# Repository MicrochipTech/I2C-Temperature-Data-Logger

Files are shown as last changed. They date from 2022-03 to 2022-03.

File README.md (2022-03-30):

# I<sup>2</sup>C Temperature Data Logger

Demo

## ABOUT
This demo implements an I<sup>2</sup>C temperature data logger. It is designed to teach the basics of I<sup>2</sup>C. The hardware uses the [**PIC18F13K50**](https://www.microchip.com/wwwproducts/en/PIC18F13K50) to communicate with the [**MCP9804**](https://www.microchip.com/wwwproducts/en/MCP9804) for the current temperature and logs that temperature using the [**24LC64**](https://www.microchip.com/wwwproducts/en/24LC64) 64-Kbit I<sup>2</sup>C Serial EEPROM. A AAA 1.5V battery, boosted to 3.3V by the [**MCP1640**](https://www.microchip.com/wwwproducts/en/MCP1640), is used to power the board. The software communicates  with the firmware using a USB Mini cable and the firmware can be programmed by using one of Microchip's many PICkit™ Programmers and Debuggers using the PICkit™ header.

### Hardware
- [**Schematic**](/Docs/Temperature%20Logger%20Schematic.pdf)
- [**BOM**](/Docs/Temperature%20Logger%20%20Bill%20of%20Materials.xls)
- [**PCB**](/PCB/I2C%20Temperature%20Logger.pdf)
- [**Gerbers**](/PCB/Gerber%20Files/05-07893-R1%20Gerbers.zip)

### Software
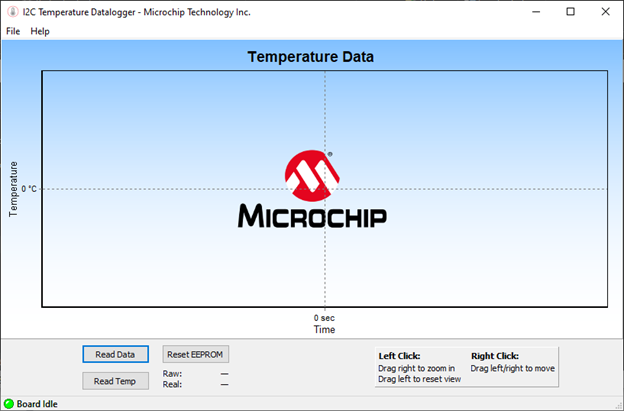
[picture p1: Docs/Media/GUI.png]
GUI

- [**Graphical User Interface**](/Software/I2C%20Temp%20Datalogger.exe)

### Firmware
- [**Firmware**](/Firmware/dist/Default/Production/Firmware.production.hex)

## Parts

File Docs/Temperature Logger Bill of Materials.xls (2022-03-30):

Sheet: BOM Report
M |  |  |  | Microchip Technology Inc. 2355 W. Chandler Blvd. Chandler, AZ 85224-6199
ASSEMBLY NUMBER: |  |  | 02-07893 | REV: | 1 |  |  |  | Bill of Materials
ASSEMBLY NAME: |  |  | PCB ASSEMBLY, I2C TEMPERATURE DATALOGGER
Item | Quantity | Designator |  | Description |  | Manufacturer | Manufacturer Part Number | Supplier | Supplier Part Number
1 | 1 | BT1 |  | HOLDER BATTERY 1CELL AAA PC MNT |  | Keystone Electronics | 2466 | Digi-Key | 2466K-ND
2 | 2 | C1, C4 |  | CAP CER 15PF 50V 5% NP0 0603 |  | TDK Corporation | C1608C0G1H150J | Digi-Key | 445-1271-1-ND
3 | 3 | C2, C5, C6 |  | CAP CER 10nF 50V 10% X7R 0603 |  | Murata Electronics North America | GRM188R71H103KA01D | Digi-Key | 490-1512-1-ND
4 | 1 | C3 |  | CAP CER 0.33uF 16V 10% X7R 0603 |  | Murata Electronics North America | GRM188R71C334KA01D | Mouser | 81-GRM188R71C334KA1D
5 | 2 | C7, C8 |  | CAP CER 10uF 6.3V X5R 20% 0805 |  | TDK Corporation | C2012X5R0J106M | Digi-Key | 445-1363-1-ND
6 | 2 | C9, C10 |  | CAP CER 2.2uF 16V Y5V -20%, +80% 0603 |  | TDK Corporation | C1608Y5V1C225Z | Digi-Key | 445-3451-1-ND
7 | 1 | D1 |  | LED CHIPLED 570NM GREEN 0603 SMD |  | OSRAM Opto Semiconductors Inc | LG Q971-KN-1 | Digi-Key | 475-1409-1-ND
8 | 1 | J1 |  | R/A BREAKAWAY HDR 6P |  | Molex | 22-28-8060 | Mouser | 538-22-28-8060
9 | 1 | J2 |  | CONN RECEPT MINI USB2.0 5POS |  | Hirose Electric Co Ltd | UX60-MB-5ST | Digi-Key | H2959CT-ND
10 | 1 | L1 |  | IND 1200mA, 4.7uH DCR Max=0.2, +/-30% |  | Wurth Electronics | 744029004 | Mouser | 710-744029004
11 | 1 | Q1 |  | MOSFET P-CH 20V 1.5A UFV |  | Toshiba | SSM5G10TU(TE85L,F) | Digi-Key | SSM5G10TU(TE85LF)CT-ND
12 | 2 | R1, R2 |  | RES 2.2K OHM 1/10W 5% 0603 SMD |  | Panasonic - ECG | ERJ-3GEYJ222V | Digi-Key | P2.2KGCT-ND
13 | 1 | R3 |  | RES 976K OHM 1/10W 1% 0603 SMD |  | Panasonic - ECG | ERJ-3EKF9763V | Digi-Key | P976KHCT-ND
14 | 1 | R4 |  | RES 562K OHM 1/10W 1% 0603 SMD |  | Panasonic - ECG | ERJ-3EKF5623V | Digi-Key | P562KHCT-ND
15 | 2 | R5, R7 |  | RES 10K OHM 1/10W 5% 0603 SMD |  | Panasonic - ECG | ERJ-3GEYJ103V | Digi-Key | P10KGCT-ND
16 | 1 | R6 |  | RES 270 OHM 1/10W 5% 0603 SMD |  | Panasonic - ECG | ERJ-3GEYJ271V | Digi-Key | P270GCT-ND
17 | 1 | U1 |  | IC PIC MCU FLASH 512KX8 20-QFN |  | Microchip Technology | PIC18F13K50-I/MQ | Microchip | PIC18F13K50-I/MQ
18 | 1 | U2 |  | IC EEPROM 64KBIT 400KHZ SOT23-5 |  | Microchip Technology | 24LC64T-E/OT | Microchip | 24LC64T-E/OT
19 | 1 | U3 |  | IC TEMP SENSOR I2C 2.7V 8DFN |  | Microchip Technology | MCP9804T-E/MC | Microchip | MCP9804T-E/MC
20 | 1 | U4 |  | IC BOOST SYNC ADJ 0.1A SOT23-6 |  | Microchip Technology | MCP1640T-I/CHY | Microchip | MCP1640T-I/CHY
21 | 1 | Y1 |  | CRYSTAL 12.000 MHZ 12PF SMD |  | TXC CORPORATION | 7V-12.000MAAE-T | Digi-Key | 887-1458-1-ND
 | 28

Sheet: Project Information
Project Full Path | C:\Memory\MASTERs\MASTERs 2012\1637I2C\Board\I2C Temperature Logger.PrjPCB
Project Filename | I2C Temperature Logger.PrjPCB
Variant Name | None
Data-Source Filename | I2C Temperature Logger.PrjPCB
Data-Source Full Path | C:\Memory\MASTERs\MASTERs 2012\1637I2C\Board\I2C Temperature Logger.PrjPCB
Title | I2C Temperature Datalogger
Total Quantity | 28
Drawing Number | 07893
Report Time | 5:13:59 PM
Report Date | 5/15/2012
Report Date & Tine | 5/15/2012 5:13:59 PM
Output Name | CM Bill of Materials
Output Type | BOM_PartType
Output Generator Name | BOM
Output Generator Description | Bill of Materials

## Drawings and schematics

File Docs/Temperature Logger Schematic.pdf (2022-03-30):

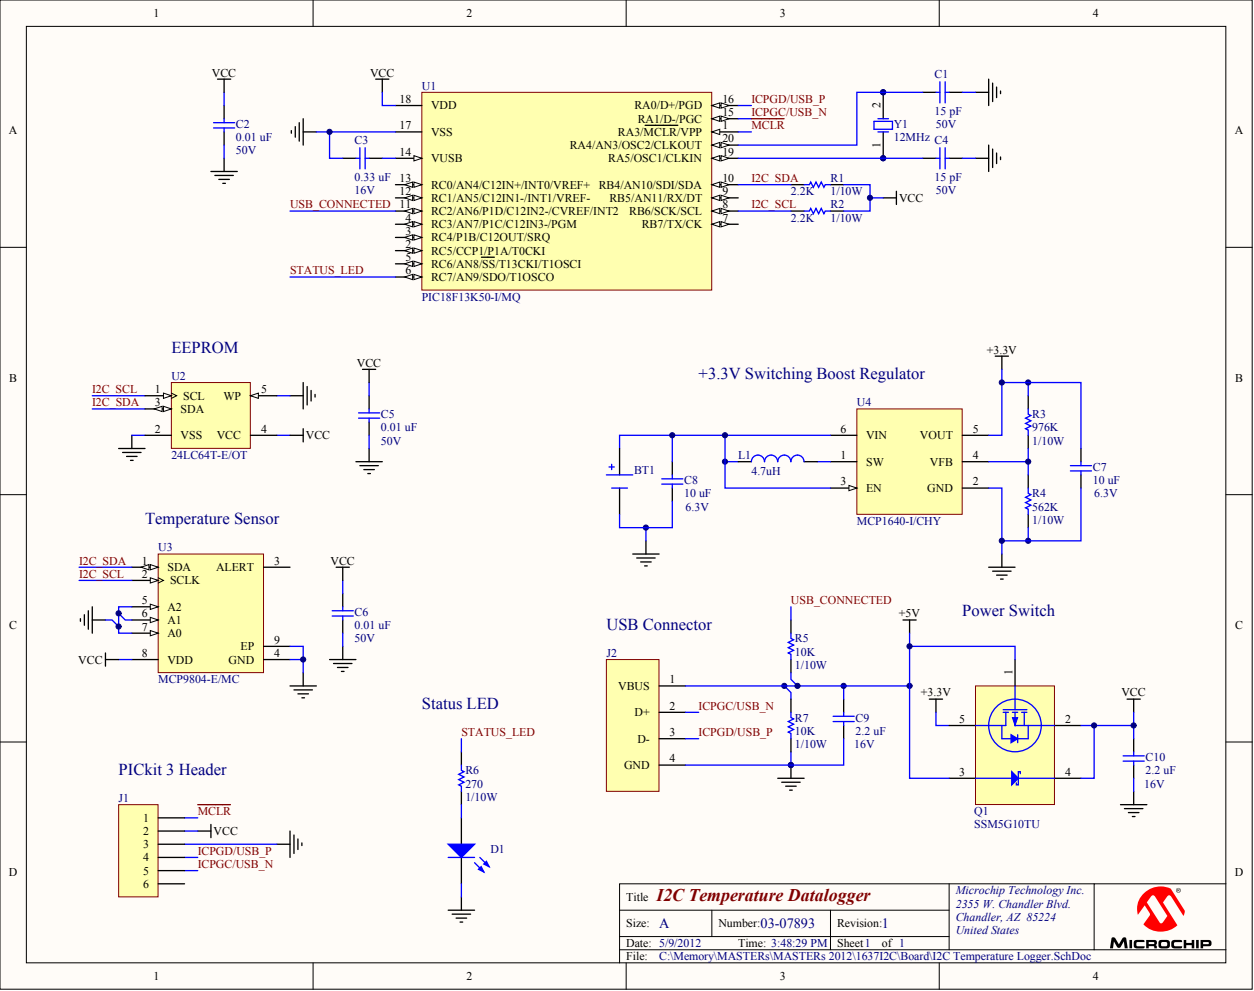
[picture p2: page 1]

Title I2C Temperature Datalogger | Microchip Technology Inc. 2355 W. Chandler Blvd. Chandler, AZ 85224 United States | 12

Size: A | Number: 03-07893 | Revision: 1
Date: 5/9/2012 Time: 3:48:29 PM | | Sheet 1 of 1

C:\Memory\MASTERs\MASTERs 2012\1637I2C\Board\I2C Temperature Logger.SchDoc

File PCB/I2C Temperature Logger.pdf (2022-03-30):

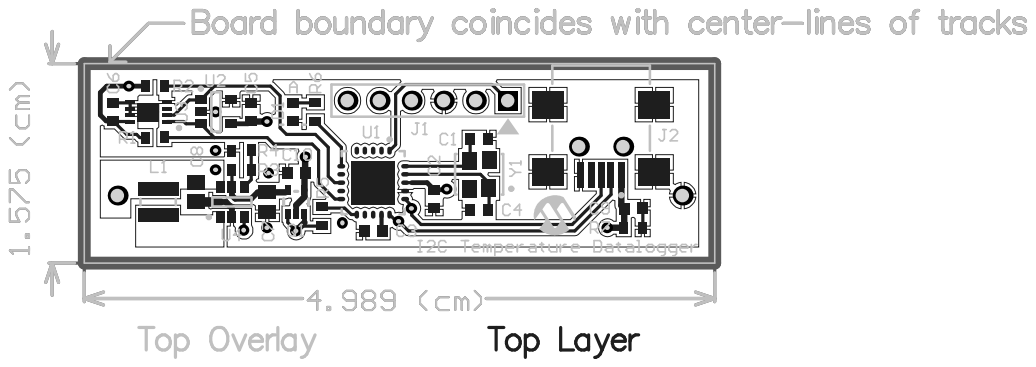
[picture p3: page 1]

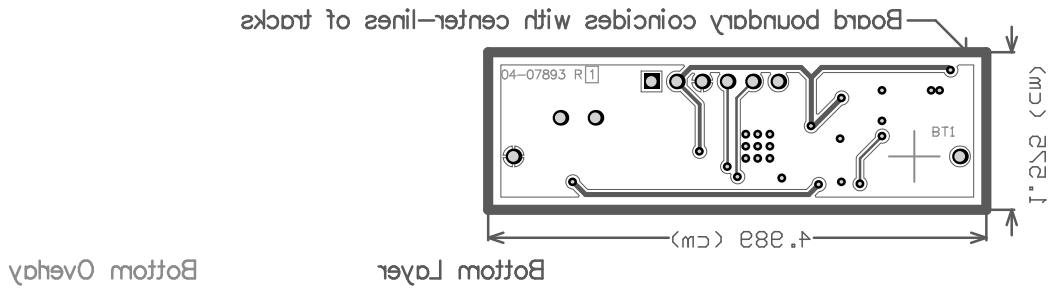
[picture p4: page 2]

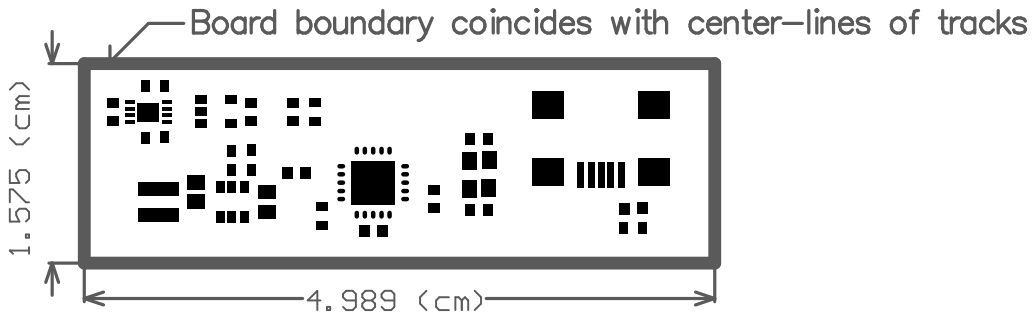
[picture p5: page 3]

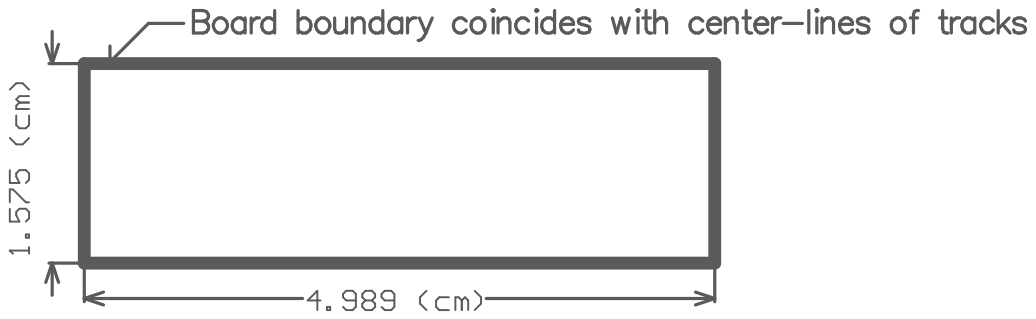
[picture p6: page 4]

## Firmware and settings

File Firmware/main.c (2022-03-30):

/*******************************************************************************
    (c) 2022 Microchip Technology Inc. and its subsidiaries.

    Subject to your compliance with these terms, you may use Microchip
    software and any derivatives exclusively with Microchip products. It is
    your responsibility to comply with third party license terms applicable to
    your use of third party software (including open source software) that may
    accompany Microchip software.

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
    IN NO EVENT WILL MICROCHIP BE LIABLE FOR ANY INDIRECT, SPECIAL, PUNITIVE,
    INCIDENTAL OR CONSEQUENTIAL LOSS, DAMAGE, COST OR EXPENSE OF ANY KIND
    WHATSOEVER RELATED TO THE SOFTWARE, HOWEVER CAUSED, EVEN IF MICROCHIP
    HAS BEEN ADVISED OF THE POSSIBILITY OR THE DAMAGES ARE FORESEEABLE. TO
    THE FULLEST EXTENT ALLOWED BY LAW, MICROCHIP'S TOTAL LIABILITY ON ALL
    CLAIMS IN ANY WAY RELATED TO THIS SOFTWARE WILL NOT EXCEED THE AMOUNT
    OF FEES, IF ANY, THAT YOU HAVE PAID DIRECTLY TO MICROCHIP FOR THIS
    SOFTWARE.
*******************************************************************************/

/** INCLUDES *******************************************************/
#include <xc.h>
#include "system.h"
#include "usb_config.h"
#include "usb.h"
#include "usb_device_hid.h"
#include "HardwareProfile.h"
#include "i2c_module.h"
#include "stdbool.h"

/** C O N S T A N T S **********************************************/
#define USB_EE_READ_CMD         0x80
#define USB_TEMP_READ_CMD       0x81
#define USB_EE_RESET_CMD        0x82

#define USB_EE_RESET_UNLOCK1    0x55
#define USB_EE_RESET_UNLOCK2    0xAA


/** T Y P E D E F S ************************************************/
typedef enum
{
    LOG_MODE,                   // Temperature logging mode
    USB_MODE                    // USB processing mode
} APP_STATES;

/** V A R I A B L E S **********************************************/

unsigned char ReceivedDataBuffer[HID_INT_OUT_EP_SIZE] @ HID_OUT_DATA_BUFFER_ADDRESS;
unsigned char ToSendDataBuffer[HID_INT_IN_EP_SIZE] @ HID_IN_DATA_BUFFER_ADDRESS;

volatile USB_HANDLE USBOutHandle = 0;
volatile USB_HANDLE USBInHandle = 0;

APP_STATES appState = LOG_MODE;

// To save power by reducing the number of EEPROM writes performed, temperature
//   temperature readings are buffered until a full EEPROM page of data is ready.
//   Then the entire buffer is written in a single operation.
uint8_t logBuffer[I2C_EEPROM_PAGE_SIZE]; // Datalogging buffer
uint8_t logBufferIndex;           // Index of current position in datalog buffer
uint16_union logEEAddress;        // Array address for next EEPROM page write

uint8_t logIntervalCount;         // Temperature reading interval counter

extern volatile USB_HANDLE USBOutHandle;
extern volatile USB_HANDLE USBInHandle;

/** P R I V A T E   P R O T O T Y P E S ****************************/
void HighPriorityISRCode(void);
void LowPriorityISRCode(void);
void InitializeSystem(void);
void UserSystemInit(void);
void LogModeInit(void);
void USBModeInit(void);
void ProcessLogIO(void);
void ProcessUSBIO(void);
void FindLastLogEntry(void);
void ResetEEPROMData(void);
void USBCBSendResume(void);
void USBCB_SOF_Handler(void);
void USBCBSuspend(void);
void USBCBWakeFromSuspend(void);
void USBCBInitEP(void);
void USBCBStdSetDscHandler(void);
void USBCBCheckOtherReq(void);
void USBCBErrorHandler(void);


MAIN_RETURN main(void)
{
    // Initialize the general system resources
    InitializeSystem();

    // Determine which state to enter initially and enter it
    if (USB_BUS_SENSE == 1)
        USBModeInit();
    else
        LogModeInit();

    while(1)
    {
        // Ensure status LED is off after any previous temperature readings
        STATUS_LED_LAT = STATUS_LED_OFF;

        // If USB cable is plugged in, then temperature readings are suspended
        //   and we're operating in data transfer mode
        if (USB_BUS_SENSE == 1)
        {
            // If we're not already in USB mode, switch to it now
            if (appState != USB_MODE)
                USBModeInit();

            // Process application-related USB tasks
            ProcessUSBIO();
        }
        // If USB cable is not plugged in, then we need to periodically read
        //   and log the current temperature
        else
        {
            // If we're not already in logging mode, switch to it now
            if (appState != LOG_MODE)
                LogModeInit();

            // Process datalogging tasks
            ProcessLogIO();

            // Datalogging-related tasks are now complete, enter idle mode until
            //   ECCP1 triggers to save power
            OSCCONbits.IDLEN = 1; // Ensure idle enable bit is set
            Sleep();            // Enter idle mode
            PIR1bits.CCP1IF = 0; // Clear CCP1IF flag for next loop
        }
    }//end while

}//end main


bool USER_USB_CALLBACK_EVENT_HANDLER(USB_EVENT event, void *pdata, uint16_t size)
{
    switch((int)event)
    {
        case EVENT_TRANSFER:
            break;

        case EVENT_SOF:            
            USBCB_SOF_Handler();
            break;

        case EVENT_SUSPEND:
            USBCBSuspend();
            break;

        case EVENT_RESUME:
            USBCBWakeFromSuspend();
            break;

        case EVENT_CONFIGURED:
            USBCBInitEP();
            break;

        case EVENT_SET_DESCRIPTOR:
            USBCBStdSetDscHandler();
            break;

        case EVENT_EP0_REQUEST:
            USBCBCheckOtherReq();
            break;

        case EVENT_BUS_ERROR:
            USBCBErrorHandler();
            break;

        case EVENT_TRANSFER_TERMINATED:
            break;

        default:
            break;
    }
    return true;
}



/********************************************************************
 * Function:        static void InitializeSystem(void)
 *
 * PreCondition:    None
 *
 * Input:           None
 *
 * Output:          None
 *
 * Side Effects:    None
 *
 * Overview:        InitializeSystem is a centralize initialization
 *                  routine. All required USB initialization routines
 *                  are called from here.
 *
 *                  User application initialization routine should
 *                  also be called from here.
 *
 * Note:            None
 *******************************************************************/
void InitializeSystem(void)
{
    // Switch from primary oscillator to internal oscillator, and disable
    //   primary oscillator and PLL to save power
    OSCCONbits.IRCF = 0x04;     // Set internal oscillator to 2 MHz
    OSCCONbits.SCS1 = 1;        // Select internal oscillator
    while (OSCCONbits.OSTS);    // Wait for clock switch to complete
    OSCCON2bits.PRI_SD = 0;     // Disable primary oscillator
    OSCTUNEbits.SPLLEN = 0;     // Disable PLL

    // Disable all analog inputs
    ANSEL = 0;
    ANSELH = 0;

//  The USB specifications require that USB peripheral devices must never source
//  current onto the Vbus pin.  Additionally, USB peripherals should not source
//  current on D+ or D- when the host/hub is not actively powering the Vbus line.
//  When designing a self powered (as opposed to bus powered) USB peripheral
//  device, the firmware should make sure not to turn on the USB module and D+
//  or D- pull up resistor unless Vbus is actively powered.  Therefore, the
//  firmware needs some means to detect when Vbus is being powered by the host.
//  A 5V tolerant I/O pin can be connected to Vbus (through a resistor), and
//  can be used to detect when Vbus is high (host actively powering), or low
//  (host is shut down or otherwise not supplying power).  The USB firmware
//  can then periodically poll this I/O pin to know when it is okay to turn on
//  the USB module/D+/D- pull up resistor.  When designing a purely bus powered
//  peripheral device, it is not possible to source current on D+ or D- when the
//  host is not actively providing power on Vbus. Therefore, implementing this
//  bus sense feature is optional.  This firmware can be made to use this bus
//  sense feature by making sure "USE_USB_BUS_SENSE_IO" has been defined in the
//  HardwareProfile.h file.
    #if defined(USE_USB_BUS_SENSE_IO)
    tris_usb_bus_sense = INPUT_PIN; // See HardwareProfile.h
    #endif

//  If the host PC sends a GetStatus (device) request, the firmware must respond
//  and let the host know if the USB peripheral device is currently bus powered
//  or self powered.  See chapter 9 in the official USB specifications for details
//  regarding this request.  If the peripheral device is capable of being both
//  self and bus powered, it should not return a hard coded value for this request.
//  Instead, firmware should check if it is currently self or bus powered, and
//  respond accordingly.  If the hardware has been configured like demonstrated
//  on the PICDEM FS USB Demo Board, an I/O pin can be polled to determine the
//  currently selected power source.  On the PICDEM FS USB Demo Board, "RA2"
//  is used for this purpose.  If using this feature, make sure "USE_SELF_POWER_SENSE_IO"
//  has been defined in HardwareProfile.h, and that an appropriate I/O pin has been mapped
//  to it in HardwareProfile.h.
    #if defined(USE_SELF_POWER_SENSE_IO)
    tris_self_power = INPUT_PIN; // See HardwareProfile.h
    #endif

    USBDeviceInit();            //usb_device.c.  Initializes USB module SFRs and firmware
                                //variables to known states.

    UserSystemInit();           // Perform app-related system initialization
}//end InitializeSystem

/******************************************************************************
 * Function:        void UserSystemInit(void)
 *
 * PreCondition:    None
 *
 * Input:           None
 *
 * Output:          None
 *
 * Side Effects:    None
 *
 * Overview:        This routine takes care of all of the application-related
 *                  system initialization.
 *
 * Note:            None
 *****************************************************************************/
void UserSystemInit(void)
{
    // Configure status LED pin
    STATUS_LED_LAT = STATUS_LED_OFF; // Turn LED off by default
    STATUS_LED_TRIS = OUTPUT_PIN; // Configure pin as an output

    // Initialize the I2C module - calculate initial baud rate based on the
    //   logging mode system clock - it will get reconfigured later
    I2C_Init((GetLogInstClock() / GetI2CLogClock()) - 1);
}//end UserSystemInit

/******************************************************************************
 * Function:        void LogModeInit(void)
 *
 * PreCondition:    None
 *
 * Input:           None
 *
 * Output:          None
 *
 * Side Effects:    None
 *
 * Overview:        This routine switches the system over to logging mode.
 *
 * Note:            None
 *****************************************************************************/
void LogModeInit(void)
{
    // Make sure USB module is disabled (safe to call every loop)
    USBDeviceDetach();

    // USB operations are suspended until cable is plugged in, so make sure
    //   internal oscillator is selected to save power
    if (OSCCONbits.OSTS)
    {
        OSCCONbits.SCS1 = 1;    // Select internal oscillator
        while (OSCCONbits.OSTS); // Wait for clock switch to complete
        OSCCON2bits.PRI_SD = 0; // Disable primary oscillator
        OSCTUNEbits.SPLLEN = 0; // Disable PLL
    }

    // Configure Timer1/ECCP1 modules for special event trigger compare mode to
    //   maintain datalogging time base
    CCPR1L = (uint8_t)(GetLogInstClock() / GetLoggingLoopClock()); // Set timebase
    CCPR1H = (uint8_t)((GetLogInstClock() / GetLoggingLoopClock()) >> 8);
    T3CONbits.T3CCP1 = 0;       // Assign Timer1 to ECCP1
    CCP1CON = 0b00001011;       // Select special event trigger compare mode
    TMR1H = 0;                  // Clear Timer1 count MSB buffer
    TMR1L = 0;                  // Clear Timer1 count LSB and latch MSB buffer
    T1CON = 0b10000000;         // Select system clock source, 1:1 prescaler, 16-bit mode
    PIR1bits.CCP1IF = 0;        // Ensure CCP1IF flag is cleared
    PIE1bits.CCP1IE = 1;        // Enable CCP1 interrupt flag to exit idle mode
    T1CONbits.TMR1ON = 1;       // Enable Timer1
    RCONbits.IPEN = 0;          // Disable interrupt priorities
    INTCONbits.PEIE = 1;        // Ensure peripheral interrupts are enabled
    INTCONbits.GIE = 0;         // Ensure global interrupts are disabled

    // Set the I2C baud rate based on the logging mode system clock
    I2C_SetBaudRate((GetLogInstClock() / GetI2CLogClock()) - 1);

    // Switch application state to logging mode
    appState = LOG_MODE;

    // Reset datalog interval counter (used to measure time between log intervals)
    logIntervalCount = 0;

    // Find last datalog entry - this automatically initializes logBuffer,
    //   logBufferIndex, and logEEAddress
    FindLastLogEntry();
}//end LogModeInit

/******************************************************************************
 * Function:        void USBModeInit(void)
 *
 * PreCondition:    None
 *
 * Input:           None
 *
 * Output:          None
 *
 * Side Effects:    None
 *
 * Overview:        This routine switches the system over to USB mode.
 *
 * Note:            None
 *****************************************************************************/
void USBModeInit(void)
{
    // Initialize the handles for the last USB transmissions
    USBOutHandle = 0;
    USBInHandle = 0;

    // Disable Timer1 and ECCP1 modules
    T1CONbits.TMR1ON = 0;       // Disable Timer1
    CCP1CON = 0;                // Disable ECCP1

    // Before proceeding with USB operation, make sure primary oscillator
    //   and PLL are enabled, stable, and selected
    if (!OSCCONbits.OSTS)
    {
        OSCCON2bits.PRI_SD = 1; // Enable primary oscillator
        OSCTUNEbits.SPLLEN = 1; // Enable PLL
        OSCCONbits.SCS1 = 0; // Select primary oscillator
        while (!OSCCONbits.OSTS); // Wait for clock switch to complete
    }

    // Set the I2C baud rate based on the USB mode system clock
    I2C_SetBaudRate((GetUSBInstClock() / GetI2CUSBClock()) - 1);

    // Make sure USB module is enabled (safe to call every loop)
    USBDeviceAttach();

    // Switch application state to USB mode
    appState = USB_MODE;
}//end USBModeInit

/********************************************************************
 * Function:        void ProcessLogIO(void)
 *
 * PreCondition:    None
 *
 * Input:           None
 *
 * Output:          None
 *
 * Side Effects:    None
 *
 * Overview:        This function handles temperature datalogging
 *                  tasks.
 *
 * Note:            None
 *******************************************************************/
void ProcessLogIO(void)
{
    // Make sure we don't go past the end of the EEPROM array
    if (logEEAddress.value >= I2C_EEPROM_DENSITY)
        return;

    // Check if next temperature reading needs to be performed
    if (++logIntervalCount >= READING_INTERVAL_COUNT)
    {
        // Turn on status LED to indicate a reading is being taken - the LED
        //   will automatically be turned off at the beginning of the next
        //   system loop, allowing it to remain on for nearly 1 loop interval
        STATUS_LED_LAT = STATUS_LED_ON;

        // Read and store temperature from sensor
        I2C_ReadTempSensorBlock(I2C_TEMPSENSOR_TEMPREG, 2, &logBuffer[logBufferIndex]);

        // Increment buffer index
        logBufferIndex += 2;

        // Increment buffer index for next reading and check if buffer is full
        if (logBufferIndex >= I2C_EEPROM_PAGE_SIZE)
        {
            // Buffer is full, dump to EEPROM
            I2C_WriteEEBlock(logEEAddress.byte.HB, logEEAddress.byte.LB,
                             I2C_EEPROM_PAGE_SIZE, logBuffer);

            // Increment EEPROM array address
            logEEAddress.value += I2C_EEPROM_PAGE_SIZE;

            // Reset buffer index
            logBufferIndex = 0;
        }

        // Reset log interval counter
        logIntervalCount = 0;
    }
}//end ProcessLogIO

/********************************************************************
 * Function:        void ProcessUSBIO(void)
 *
 * PreCondition:    None
 *
 * Input:           None
 *
 * Output:          None
 *
 * Side Effects:    None
 *
 * Overview:        This function handles application-related USB
 *                  tasks.
 *
 * Note:            None
 *******************************************************************/
void ProcessUSBIO(void)
{
    // If USB module is not yet in a configured state or if it's suspended, then
    //   do not proceed
    if ((USBDeviceState < CONFIGURED_STATE)||(USBSuspendControl==1))
        return;

    if (!HIDRxHandleBusy(USBOutHandle))             // Check if data was received from the host
    {
        // USB data was received from host - process it here
        switch (ReceivedDataBuffer[0])              // Check byte 0 for command value
        {
            case USB_EE_READ_CMD:                   // EEPROM read command received
                // Ensure HIDTxHandle is not busy
                while (HIDTxHandleBusy(USBInHandle));

                // Read HID_INT_IN_EP_SIZE bytes from EEPROM starting at address
                //   specified by command, storing result in USB data buffer
                I2C_ReadEEBlock(ReceivedDataBuffer[2], ReceivedDataBuffer[1],
                                HID_INT_IN_EP_SIZE, ToSendDataBuffer);

                // Initiate the USB transfer back to the host
                USBInHandle = HIDTxPacket(HID_EP,(uint8_t*)&ToSendDataBuffer,HID_INT_IN_EP_SIZE);
                break;

            case USB_TEMP_READ_CMD:                 // Temp sensor read command received
                // Ensure HIDTxHandle is not busy
                while (HIDTxHandleBusy(USBInHandle));

                // Read current temperature from sensor - note that temp reading
                //   only requires 2 bytes in the buffer, so the remaining
                //   (HID_INT_IN_EP_SIZE - 2) bytes are undefined and should be
                //   ignored by the host
                I2C_ReadTempSensorBlock(I2C_TEMPSENSOR_TEMPREG, 2, ToSendDataBuffer);

                // Initiate the USB transfer back to the host
                USBInHandle = HIDTxPacket(HID_EP,(uint8_t*)&ToSendDataBuffer,HID_INT_IN_EP_SIZE);
                break;

            case USB_EE_RESET_CMD:                  // EEPROM reset command received
                // Verify unlock values
                if (ReceivedDataBuffer[1] == USB_EE_RESET_UNLOCK1 &&
                    ReceivedDataBuffer[2] == USB_EE_RESET_UNLOCK2)
                {
                    // Unlock values are valid, reset EEPROM by filling the entire
                    //   EEPROM array with a known pattern to mark data as invalid
                    ResetEEPROMData();

                    // Indicate to host that sequence was valid
                    ToSendDataBuffer[0] = USB_EE_RESET_CMD;
                    ToSendDataBuffer[1] = 1;
                }
                else
                {
                    // Indicate to host that sequence was not valid
                    ToSendDataBuffer[0] = USB_EE_RESET_CMD;
                    ToSendDataBuffer[1] = 0;
                }

                // Initiate the USB transfer back to the host
                USBInHandle = HIDTxPacket(HID_EP,(uint8_t*)&ToSendDataBuffer,HID_INT_IN_EP_SIZE);
                break;
        }

        // Re-arm the OUT endpoint for the next packet
        USBOutHandle = HIDRxPacket(HID_EP,(uint8_t*)&ReceivedDataBuffer,HID_INT_OUT_EP_SIZE);
    }
}//end ProcessUSBIO
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

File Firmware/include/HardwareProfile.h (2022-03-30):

/*******************************************************************************
    Filename:       HardwareProfile.h
    Dependencies:   See INCLUDES section
    Processor:      PIC18F13K50
    Hardware:       This demo implements an I2C temperature data logger. It is 
                    designed to teach the basics of I2C.
    Complier:       Microchip XC8 V2.35
    Company:        Microchip Technology Inc.
*******************************************************************************/
/*******************************************************************************
    (c) 2022 Microchip Technology Inc. and its subsidiaries.

    Subject to your compliance with these terms, you may use Microchip
    software and any derivatives exclusively with Microchip products. It is
    your responsibility to comply with third party license terms applicable to
    your use of third party software (including open source software) that may
    accompany Microchip software.

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
    IN NO EVENT WILL MICROCHIP BE LIABLE FOR ANY INDIRECT, SPECIAL, PUNITIVE,
    INCIDENTAL OR CONSEQUENTIAL LOSS, DAMAGE, COST OR EXPENSE OF ANY KIND
    WHATSOEVER RELATED TO THE SOFTWARE, HOWEVER CAUSED, EVEN IF MICROCHIP
    HAS BEEN ADVISED OF THE POSSIBILITY OR THE DAMAGES ARE FORESEEABLE. TO
    THE FULLEST EXTENT ALLOWED BY LAW, MICROCHIP'S TOTAL LIABILITY ON ALL
    CLAIMS IN ANY WAY RELATED TO THIS SOFTWARE WILL NOT EXCEED THE AMOUNT
    OF FEES, IF ANY, THAT YOU HAVE PAID DIRECTLY TO MICROCHIP FOR THIS
    SOFTWARE.
*******************************************************************************/
/*******************************************************************************
    File Description:
 
    Change History:
        Rev   Description
        ----  -----------------------------------------
        1.0   Initial release
        2.0   General code cleanup, no functional change
*******************************************************************************/

#ifndef __HARDWARE_PROFILE_H
#define __HARDWARE_PROFILE_H

/*******************************************************************/
/******** USB stack hardware selection options *********************/
/*******************************************************************/
//This section is the set of definitions required by the MCHPFSUSB
//  framework.  These definitions tell the firmware what mode it is
//  running in, and where it can find the results to some information
//  that the stack needs.
//These definitions are required by every application developed with
//  this revision of the MCHPFSUSB framework.  Please review each
//  option carefully and determine which options are desired/required
//  for your application.

#define self_power              0

#define USE_USB_BUS_SENSE_IO
#define tris_usb_bus_sense      TRISCbits.TRISC2
#define USB_BUS_SENSE           PORTCbits.RC2

/*******************************************************************/
/** Application specific definitions *******************************/
/*******************************************************************/

// Clock frequency constants - when in logging mode, HF internal oscillator
//   divided down to 2 MHz is selected. When in USB mode, primary oscillator
//   boosted to 48 MHz via PLL then divided down to 12 MHz is selected.
#define LOG_SYS_CLOCK_FREQ      (2000000ul)
#define GetLogSystemClock()     (LOG_SYS_CLOCK_FREQ)
#define GetLogInstClock()       (GetLogSystemClock()/4)
#define USB_SYS_CLOCK_FREQ      (12000000ul)
#define GetUSBSystemClock()     (USB_SYS_CLOCK_FREQ)
#define GetUSBInstClock()       (GetUSBSystemClock()/4)

// Datalogging timebase frequency (in Hz) - this determines how often the system
//   runs through the main loop when in datalogging mode
#define GetLoggingLoopClock()   (50)
// READING_INTERVAL_COUNT defines how many times the main system loop must
//   iterate before a temperature reading is taken.
//   Examples:
//   (GetLoggingLoopClock() * 5) = 1 reading every 5 seconds
//   (GetLoggingLoopClock() / 1) = 1 reading per second
//   (GetLoggingLoopClock() / 2) = 2 readings per second
//   (GetLoggingLoopClock() / 5) = 5 readings per second
#define READING_INTERVAL_COUNT  (GetLoggingLoopClock() / 1)

// I2C clock frequencies - in logging mode, the MCU is not running fast enough
//   to support 400 kHz
#define GetI2CLogClock()        (250000ul)
#define GetI2CUSBClock()        (400000ul)

/** I 2 C   P E R I P H E R A L   D E F I N I T I O N S ************/
#define I2C_EEPROM_PAGE_SIZE    (32)
#define I2C_EEPROM_WRITE_ADDR   (0xA0)
#define I2C_EEPROM_READ_ADDR    (I2C_EEPROM_WRITE_ADDR | 0x01)
#define I2C_EEPROM_DENSITY      (0x2000)
#define I2C_EEPROM_TWC_MS       (5)

#define I2C_TEMP_WRITE_ADDR     (0x30)
#define I2C_TEMP_READ_ADDR      (I2C_TEMP_WRITE_ADDR | 0x01)
#define I2C_TEMPSENSOR_TEMPREG  (0x05)
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
